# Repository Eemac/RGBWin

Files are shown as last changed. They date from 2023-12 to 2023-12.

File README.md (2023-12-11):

# RGBWin!!
A kW-scale RGBW LED controller for indoor effect lighting. I designed this board in my sophomore year of high school because no low-cost, highly-programmable RGBW solution existed at the time. The two TSSOP parts (PCA9685 16ch PWM controllers) were the first SMT parts I soldered. 

RGB_CTL

## Schematic
My second time using Autodesk Eagle. I didn't know pin labels were a thing, so all wires are directly routed from input to output. I'm so sorry! :P Also, an interesting story about the big power MOSFETs: the only ones I could find that were in my budget came from an obscure eBay listing. I ended up waiting about a month just to put the final parts on the board because shipping took so long! 
Screenshot 2023-12-10 at 8 38 13 PM

## PCB
A fairly decent design, I think. I didn't know about ground pours at the time, so I manually routed large ground traces to all of the power MOSFETs.
PCB

## Design Files/Code, should anyone want.
Provided in the `project` folder.
The Arduino code includes two libraries: `Thread` (https://www.arduino.cc/reference/en/libraries/thread/), and `PCA9685` (https://www.arduino.cc/reference/en/libraries/pca9685-16-channel-pwm-driver-module-library/). These two links have installation instructions and are supported by the Arduino Library manager.

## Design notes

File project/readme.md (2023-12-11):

# Project files

Eagle board/schematic files included as well as a test Arduino .ino file

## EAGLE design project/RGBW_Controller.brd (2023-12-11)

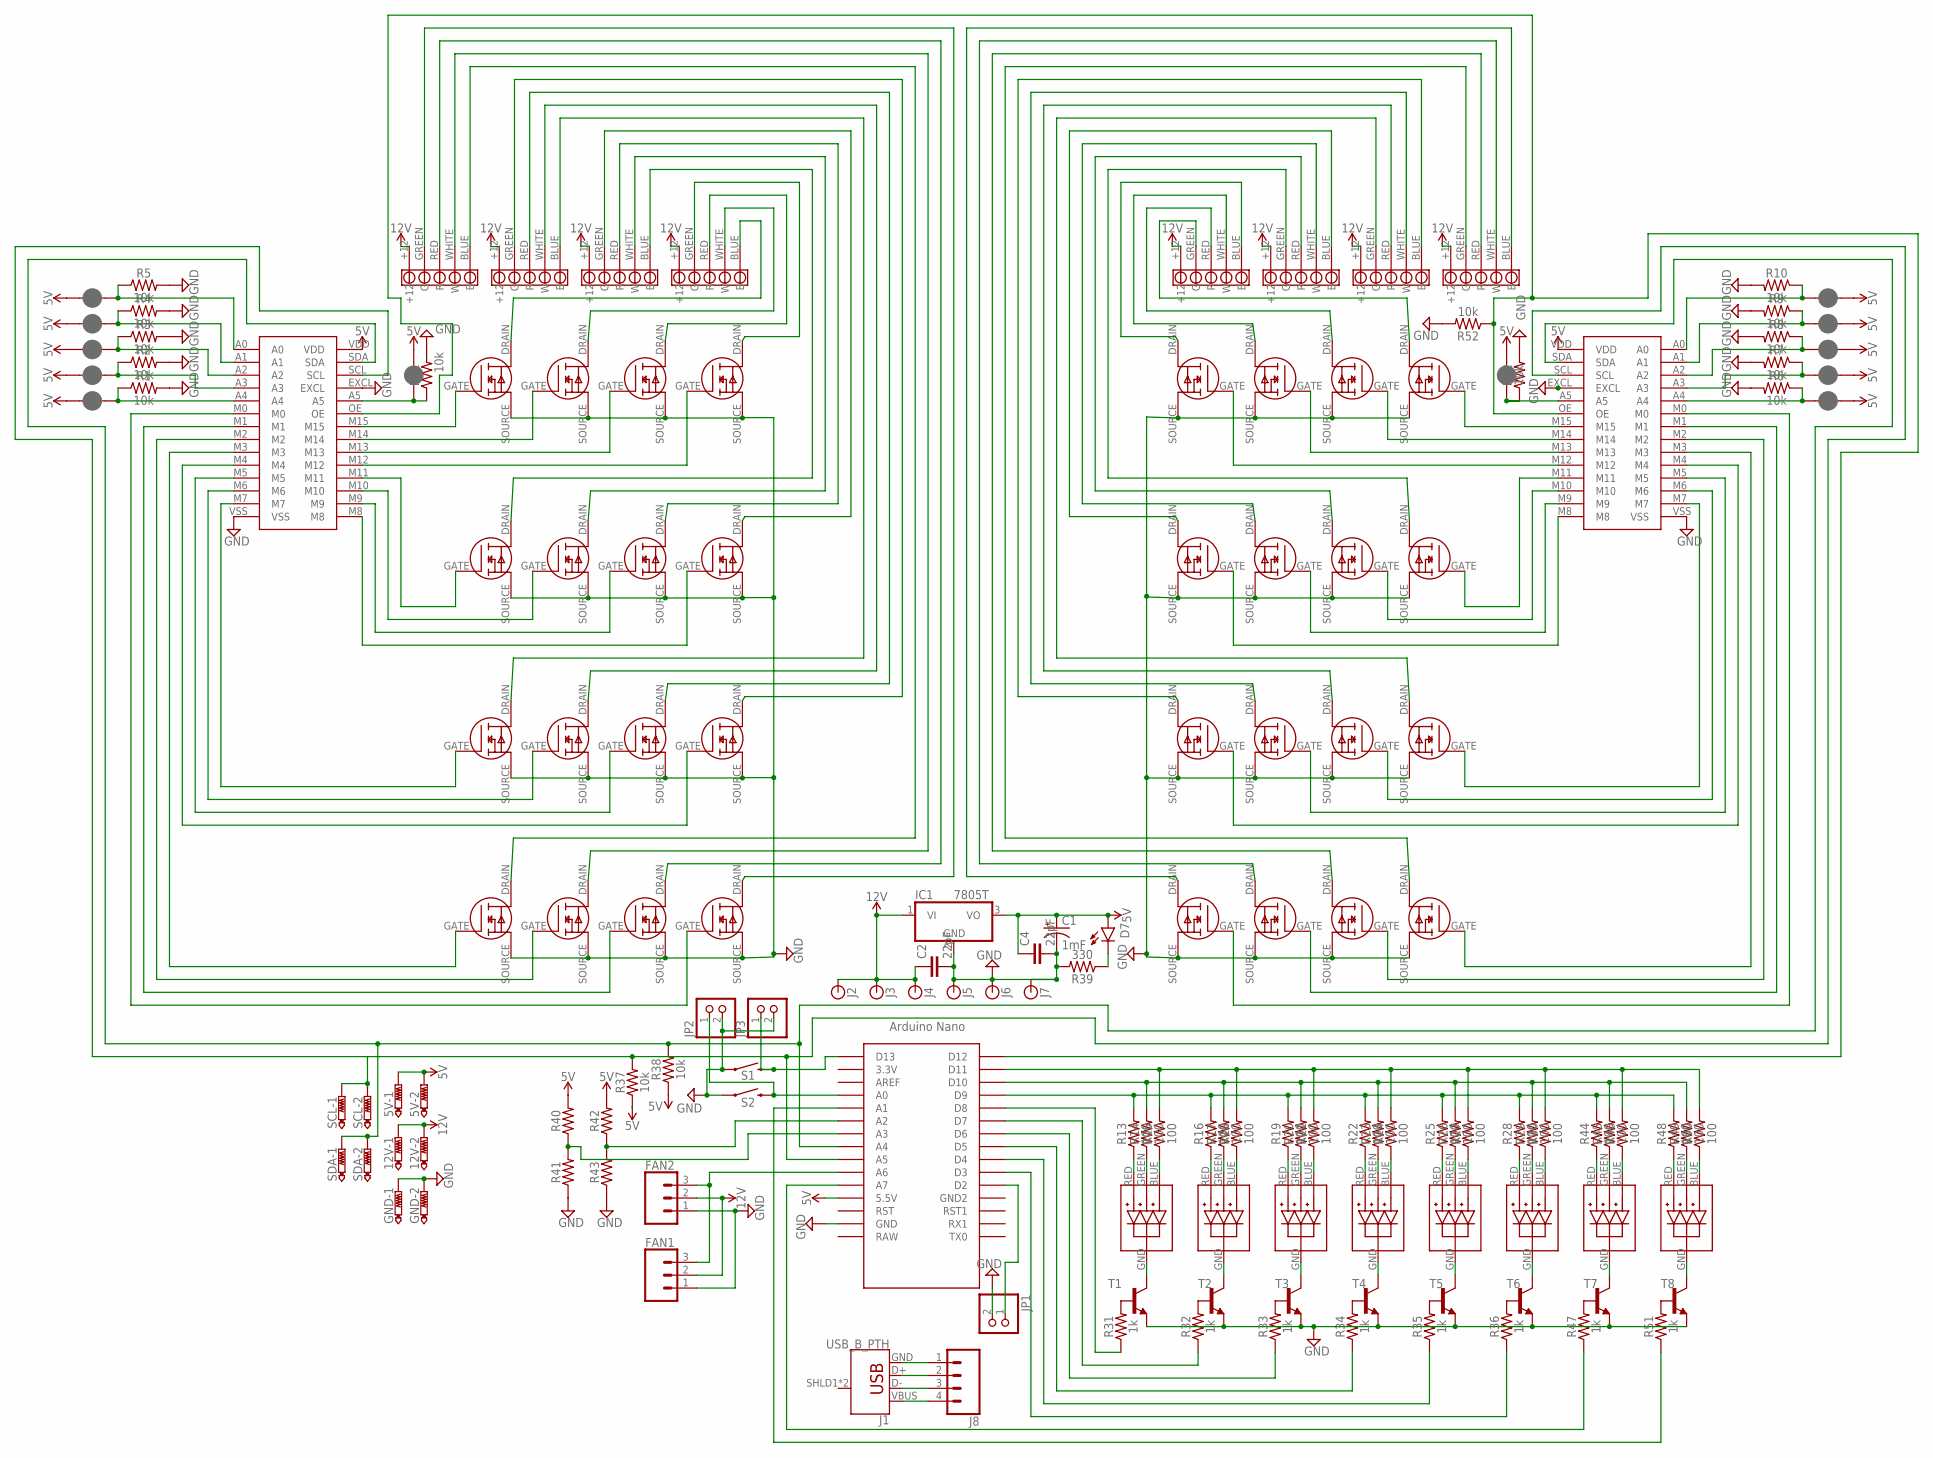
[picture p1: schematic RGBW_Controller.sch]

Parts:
5V, 12V: PTR2; P2-38-17
C1: 1mF; CPOL-RADIAL-5MM-10MM
C2, C4: 22pF; CAP-PTH-2.54
D7: LED5MM; LED_5MM
FAN1, FAN2: CONN_03; 1X03
GND: PTR2; P2-38-17
IC1: 7805T; TO220H
J1: USB_B_PTH; USB-B-PTH
J1_, J2_, J3_, J4_, J5_, J6_, J7_, J8_, J9_, J10_, J11_, J12_: JUMPER-SMT_2_NC_PASTE_SILK; SMT-JUMPER_2_NC_PASTE_SILK
J2, J3, J4, J5, J6, J7: BANANA_CONN
J8: CONN_04; 1X04
JP1, JP2, JP3: PINHD-1X2; 1X02
R1, R2, R3, R4, R5, R6, R7, R8, R9, R10, R11, R12, R37, R38, R52: 10k; AXIAL-0.3
R13, R14, R15, R16, R17, R18, R19, R20, R21, R22, R23, R24, R25, R26, R27, R28, R29, R30, R44, R45, R46, R48, R49, R50: 100; AXIAL-0.3
R31, R32, R33, R34, R35, R36, R47, R51: 1k; AXIAL-0.3
R39: 330; AXIAL-0.3
R40, R42: 10; AXIAL-0.1
R41, R43: 10; AXIAL-0.3
S1, S2: MOMENTARY-SWITCH-SPST-PTH-6.0MM; TACTILE_SWITCH_PTH_6.0MM
SCL: PTR2; P2-38-17
SDA: PTR2; P2-38-17
T1, T2, T3, T4, T5, T6, T7, T8: -NPN-TO92-EBC; TO92-EBC
U$1, U$18: 16CH_PWM
U$2, U$3, U$4, U$5, U$6, U$7, U$8, U$9, U$10, U$11, U$12, U$13, U$14, U$15, U$16, U$17, U$19, U$20, U$21, U$22, U$23, U$24, U$25, U$26, U$27, U$28, U$29, U$30, U$31, U$32, U$33, U$34: MOSFET
U$35: NANO
U$36, U$45, U$46, U$47, U$48, U$49, U$50, U$51: 5MM_RGB; 5MMRGB
U$37, U$38, U$39, U$40, U$41, U$42, U$43, U$44: 5POLE_TERM

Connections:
5V: 5V.TP-1, 5V.TP-2, C1.+, C4.1, D7.A, IC1.3 (VO), J1_.1, J2_.1, J3_.1, J4_.1, J5_.1, J6_.1, J7_.1, J8_.1, J9_.1, J10_.1, J11_.1, J12_.1, R37.P$1 (1), R38.P$1 (1), R40.P$2 (2), R42.P$2 (2), U$1.VDD, U$18.VDD, U$35.5V (5.5V)
12V: 12V.TP-1, 12V.TP-2, C2.1, FAN1.2, FAN2.2, IC1.1 (VI), J2.P$1, J3.P$1, J4.P$1, U$37.+12, U$38.+12, U$39.+12, U$40.+12, U$41.+12, U$42.+12, U$43.+12, U$44.+12
GND: C1.-, C2.2, C4.2, FAN1.1, FAN2.1, GND.TP-1, GND.TP-2, IC1.2 (GND), J5.P$1, J6.P$1, J7.P$1, JP1.2, JP2.2, JP3.2, R1.P$2 (2), R2.P$2 (2), R3.P$2 (2), R4.P$2 (2), R5.P$2 (2), R6.P$2 (2), R7.P$2 (2), R8.P$2 (2), R9.P$2 (2), R10.P$2 (2), R11.P$2 (2), R12.P$2 (2), R39.P$2 (2), R41.P$1 (1), R43.P$1 (1), R52.P$2 (2), S1.1, S2.1, T1.E, T2.E, T3.E, T4.E, T5.E, T6.E, T7.E, T8.E, U$1.EXCL, U$1.VSS, U$2.SOURCE, U$3.SOURCE, U$4.SOURCE, U$5.SOURCE, U$6.SOURCE, U$7.SOURCE, U$8.SOURCE, U$9.SOURCE, U$10.SOURCE, U$11.SOURCE, U$12.SOURCE, U$13.SOURCE, U$14.SOURCE, U$15.SOURCE, U$16.SOURCE, U$17.SOURCE, U$18.EXCL, U$18.VSS, U$19.SOURCE, U$20.SOURCE, U$21.SOURCE, U$22.SOURCE, U$23.SOURCE, U$24.SOURCE, U$25.SOURCE, U$26.SOURCE, U$27.SOURCE, U$28.SOURCE, U$29.SOURCE, U$30.SOURCE, U$31.SOURCE, U$32.SOURCE, U$33.SOURCE, U$34.SOURCE, U$35.GND
unnamed: J12_.2, R12.P$1 (1), U$18.A5
unnamed: R15.P$2 (2), R18.P$2 (2), R21.P$2 (2), R24.P$2 (2), R27.P$2 (2), R30.P$2 (2), R46.P$2 (2), R50.P$2 (2), U$35.D11
unnamed: R13.P$1 (1), U$36.RED
unnamed: R14.P$1 (1), U$36.GREEN
unnamed: J6_.2, R11.P$1 (1), U$1.A5
unnamed: R15.P$1 (1), U$36.BLUE
unnamed: U$18.M15, U$19.GATE
unnamed: U$18.M14, U$20.GATE
unnamed: U$18.M13, U$21.GATE
unnamed: U$1.M15, U$2.GATE
unnamed: U$1.M14, U$3.GATE
unnamed: U$1.M13, U$4.GATE
unnamed: U$1.M12, U$5.GATE
unnamed: D7.K (C), R39.P$1 (1)
unnamed: U$2.DRAIN, U$43.BLUE (B)
unnamed: R16.P$1 (1), U$45.RED
unnamed: R17.P$1 (1), U$45.GREEN
unnamed: J1_.2, R5.P$1 (1), U$1.A0
unnamed: U$1.M11, U$6.GATE
unnamed: U$1.M10, U$7.GATE
unnamed: U$1.M9, U$8.GATE
unnamed: U$1.M8, U$9.GATE
unnamed: R18.P$1 (1), U$45.BLUE
unnamed: R19.P$1 (1), U$46.RED
unnamed: R20.P$1 (1), U$46.GREEN
unnamed: R21.P$1 (1), U$46.BLUE
unnamed: U$18.M12, U$22.GATE
unnamed: U$1.M7, U$10.GATE
unnamed: U$1.M6, U$11.GATE
unnamed: U$1.M5, U$12.GATE
unnamed: U$1.M4, U$13.GATE
unnamed: R22.P$1 (1), U$47.RED
unnamed: R23.P$1 (1), U$47.GREEN
unnamed: R24.P$1 (1), U$47.BLUE
unnamed: R25.P$1 (1), U$48.RED
unnamed: U$22.DRAIN, U$44.BLUE (B)
unnamed: U$1.M3, U$14.GATE
unnamed: U$1.M2, U$15.GATE
unnamed: U$1.M1, U$16.GATE
unnamed: U$1.M0, U$17.GATE
unnamed: R26.P$1 (1), U$48.GREEN
unnamed: R27.P$1 (1), U$48.BLUE
unnamed: R28.P$1 (1), U$49.RED
unnamed: R29.P$1 (1), U$49.GREEN
unnamed: U$21.DRAIN, U$44.WHITE (W)
unnamed: U$20.DRAIN, U$44.RED (R)
unnamed: U$19.DRAIN, U$44.GREEN (G)
unnamed: J2_.2, R4.P$1 (1), U$1.A1
unnamed: U$18.M11, U$23.GATE
unnamed: U$18.M10, U$24.GATE
unnamed: U$18.M9, U$25.GATE
unnamed: U$18.M8, U$26.GATE
unnamed: U$26.DRAIN, U$42.BLUE (B)
unnamed: U$25.DRAIN, U$42.WHITE (W)
unnamed: U$24.DRAIN, U$42.RED (R)
unnamed: U$23.DRAIN, U$42.GREEN (G)
unnamed: U$18.M7, U$27.GATE
unnamed: U$18.M6, U$28.GATE
unnamed: U$18.M5, U$29.GATE
unnamed: U$18.M4, U$30.GATE
unnamed: U$30.DRAIN, U$41.BLUE (B)
unnamed: U$29.DRAIN, U$41.WHITE (W)
unnamed: U$28.DRAIN, U$41.RED (R)
unnamed: U$27.DRAIN, U$41.GREEN (G)
unnamed: U$18.M3, U$31.GATE
unnamed: U$18.M2, U$32.GATE
unnamed: U$18.M1, U$33.GATE
unnamed: U$18.M0, U$34.GATE
unnamed: U$34.DRAIN, U$40.BLUE (B)
unnamed: U$33.DRAIN, U$40.WHITE (W)
unnamed: U$32.DRAIN, U$40.RED (R)
unnamed: U$31.DRAIN, U$40.GREEN (G)
unnamed: R30.P$1 (1), U$49.BLUE
unnamed: JP3.1, S1.3 (2), U$35.D13
unnamed: JP2.1, S2.3 (2), U$35.A0
unnamed: T6.C, U$49.GND
unnamed: T5.C, U$48.GND
unnamed: T4.C, U$47.GND
unnamed: J3_.2, R3.P$1 (1), U$1.A2
unnamed: J4_.2, R2.P$1 (1), U$1.A3
unnamed: J5_.2, R1.P$1 (1), U$1.A4
unnamed: J7_.2, R10.P$1 (1), U$18.A0
unnamed: J8_.2, R9.P$1 (1), U$18.A1
unnamed: J9_.2, R8.P$1 (1), U$18.A2
unnamed: J10_.2, R7.P$1 (1), U$18.A3
unnamed: J11_.2, R6.P$1 (1), U$18.A4
unnamed: T3.C, U$46.GND
unnamed: T2.C, U$45.GND
unnamed: T1.C, U$36.GND
unnamed: J1.GND, J8.1
unnamed: J1.VBUS, J8.4
unnamed: J1.D-, J8.3
unnamed: J1.D+, J8.2
unnamed: R40.P$1 (1), R41.P$2 (2), U$35.A3
unnamed: R42.P$1 (1), R43.P$2 (2), U$35.A2
unnamed: FAN1.3, FAN2.3, U$35.A6
unnamed: R52.P$1 (1), U$1.OE, U$18.OE, U$35.D12
unnamed: R13.P$2 (2), R16.P$2 (2), R19.P$2 (2), R22.P$2 (2), R25.P$2 (2), R28.P$2 (2), R44.P$2 (2), R48.P$2 (2), U$35.D9
unnamed: JP1.1, U$35.D2
unnamed: R37.P$2 (2), SCL.TP-1, SCL.TP-2, U$1.SCL, U$18.SCL, U$35.A5
unnamed: R38.P$2 (2), SDA.TP-1, SDA.TP-2, U$1.SDA, U$18.SDA, U$35.A4
unnamed: R47.P$2 (2), T7.B
unnamed: R47.P$1 (1), U$35.A7
unnamed: R44.P$1 (1), U$50.RED
unnamed: R45.P$1 (1), U$50.GREEN
unnamed: R46.P$1 (1), U$50.BLUE
unnamed: R31.P$1 (1), U$35.D8
unnamed: R31.P$2 (2), T1.B
unnamed: R32.P$2 (2), T2.B
unnamed: R33.P$2 (2), T3.B
unnamed: R34.P$2 (2), T4.B
unnamed: R35.P$2 (2), T5.B
unnamed: R36.P$2 (2), T6.B
unnamed: R32.P$1 (1), U$35.D7
unnamed: R33.P$1 (1), U$35.D6
unnamed: R34.P$1 (1), U$35.D5
unnamed: R35.P$1 (1), U$35.D4
unnamed: R36.P$1 (1), U$35.D3
unnamed: U$17.DRAIN, U$37.GREEN (G)
unnamed: U$16.DRAIN, U$37.RED (R)
unnamed: U$15.DRAIN, U$37.WHITE (W)
unnamed: U$14.DRAIN, U$37.BLUE (B)
unnamed: T7.C, U$50.GND
unnamed: U$13.DRAIN, U$38.GREEN (G)
unnamed: U$12.DRAIN, U$38.RED (R)
unnamed: U$11.DRAIN, U$38.WHITE (W)
unnamed: U$10.DRAIN, U$38.BLUE (B)
unnamed: U$9.DRAIN, U$39.GREEN (G)
unnamed: U$8.DRAIN, U$39.RED (R)
unnamed: U$7.DRAIN, U$39.WHITE (W)
unnamed: U$6.DRAIN, U$39.BLUE (B)
unnamed: U$5.DRAIN, U$43.GREEN (G)
unnamed: U$4.DRAIN, U$43.RED (R)
unnamed: U$3.DRAIN, U$43.WHITE (W)
unnamed: R14.P$2 (2), R17.P$2 (2), R20.P$2 (2), R23.P$2 (2), R26.P$2 (2), R29.P$2 (2), R45.P$2 (2), R49.P$2 (2), U$35.D10
unnamed: R51.P$2 (2), T8.B
unnamed: R51.P$1 (1), U$35.A1
unnamed: R48.P$1 (1), U$51.RED
unnamed: R49.P$1 (1), U$51.GREEN
unnamed: R50.P$1 (1), U$51.BLUE
unnamed: T8.C, U$51.GND

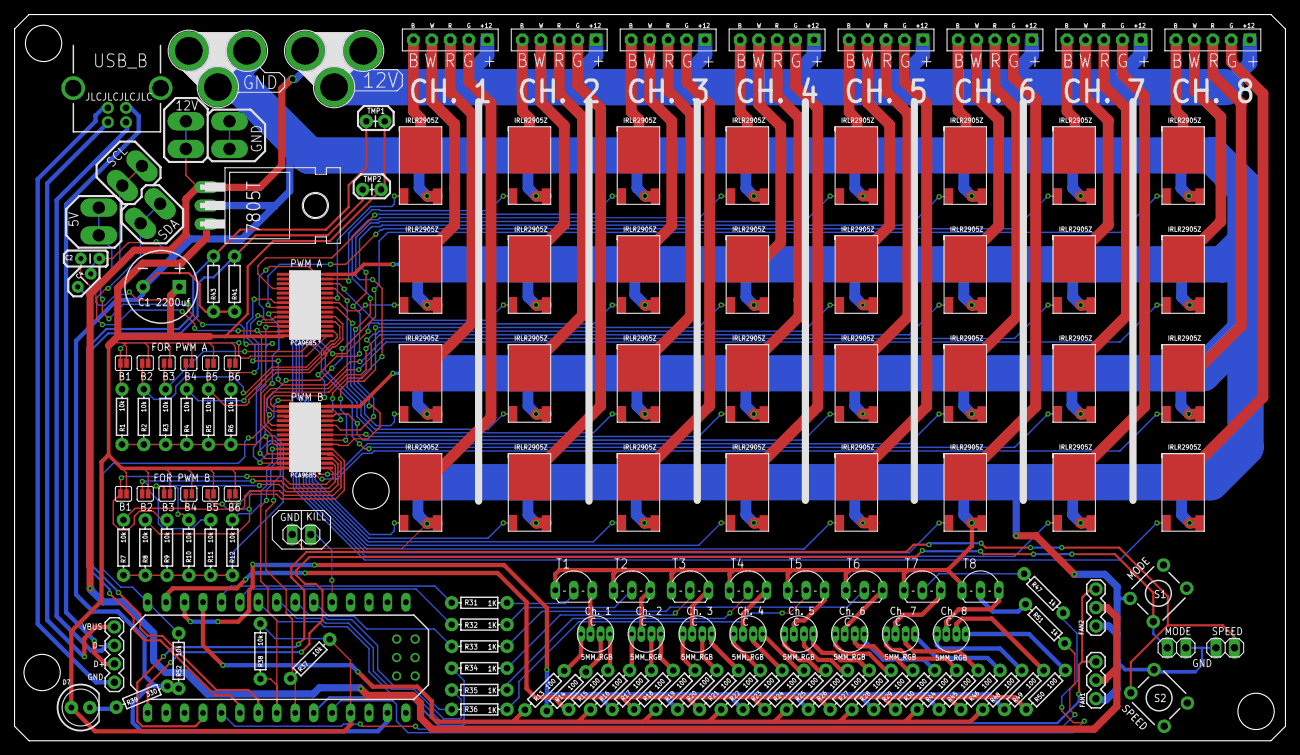
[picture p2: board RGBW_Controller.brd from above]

Board: 2 copper layers, 175.0 x 100.0 mm, 148 parts (0 on the bottom side), 144 nets.

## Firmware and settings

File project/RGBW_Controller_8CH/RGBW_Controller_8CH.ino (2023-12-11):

#include <Wire.h>
#include <PCA9685.h>
#include <Thread.h>

PCA9685 pwm1;
PCA9685 pwm2;

Thread StatusRGB = Thread();

String newLed;

int n = 0;
int tickSpeed = 4;
int allUpTickCounter = 0;
int updateChannel = 0;

static const uint8_t StatusChannel[] = {8, 7, 6, 5, 4, 3, A3, A1};
int statusCounter = 0;

int StatusCh1[] = {0,0,0,0};
int StatusCh2[] = {0,0,0,0};
int StatusCh3[] = {0,0,0,0};
int StatusCh4[] = {0,0,0,0};
int StatusCh5[] = {0,0,0,0};
int StatusCh6[] = {0,0,0,0};
int StatusCh7[] = {0,0,0,0};
int StatusCh8[] = {0,0,0,0};

//Change 1 Ch    0-8       0-4096    0-4096    0-4096    0-4096
void tickRGB(int channel, int red, int green, int blue, int white) { 
    //channel range = 0-7 (1,2,3,7 on pwm1) (4,5,6,8 on pwm2)
    //color ranges = 0-4096
    
    if (channel == 1)
    {
      pwm1.setChannelPWM(3, blue);
      pwm1.setChannelPWM(2, white);
      pwm1.setChannelPWM(1, red);
      pwm1.setChannelPWM(0, green);
      
      StatusCh1[0] = blue;
      StatusCh1[1] = white;
      StatusCh1[2] = red;
      StatusCh1[3] = green;
    }
    if (channel == 2)
    {
      pwm1.setChannelPWM(7, blue);
      pwm1.setChannelPWM(6, white);
      pwm1.setChannelPWM(5, red);
      pwm1.setChannelPWM(4, green);
      
      StatusCh2[0] = blue;
      StatusCh2[1] = white;
      StatusCh2[2] = red;
      StatusCh2[3] = green;
    }
    if (channel == 3)
    {
      pwm1.setChannelPWM(11, blue);
      pwm1.setChannelPWM(10, white);
      pwm1.setChannelPWM(9, red);
      pwm1.setChannelPWM(8, green);

      StatusCh3[0] = blue;
      StatusCh3[1] = white;
      StatusCh3[2] = red;
      StatusCh3[3] = green;
    }
    if (channel == 4)
    {
      pwm2.setChannelPWM(0, blue);
      pwm2.setChannelPWM(1, white);
      pwm2.setChannelPWM(2, red);
      pwm2.setChannelPWM(3, green);
      
      StatusCh4[0] = blue;
      StatusCh4[1] = white;
      StatusCh4[2] = red;
      StatusCh4[3] = green;
    }
    if (channel == 5)
    {
      pwm2.setChannelPWM(4, blue);
      pwm2.setChannelPWM(5, white);
      pwm2.setChannelPWM(6, red);
      pwm2.setChannelPWM(7, green);
      
      StatusCh5[0] = blue;
      StatusCh5[1] = white;
      StatusCh5[2] = red;
      StatusCh5[3] = green;
    }
    if (channel == 6)
    {
      pwm2.setChannelPWM(8, blue);
      pwm2.setChannelPWM(9, white);
      pwm2.setChannelPWM(10, red);
      pwm2.setChannelPWM(11, green);
      
      StatusCh6[0] = blue;
      StatusCh6[1] = white;
      StatusCh6[2] = red;
      StatusCh6[3] = green;
    }
    if (channel == 7)
    {
      pwm1.setChannelPWM(15, blue);
      pwm1.setChannelPWM(14, white);
      pwm1.setChannelPWM(13, red);
      pwm1.setChannelPWM(12, green);
      
      StatusCh7[0] = blue;
      StatusCh7[1] = white;
      StatusCh7[2] = red;
      StatusCh7[3] = green;
    }
    if (channel == 8)
    {
      pwm2.setChannelPWM(12, blue);
      pwm2.setChannelPWM(13, white);
      pwm2.setChannelPWM(14, red);
      pwm2.setChannelPWM(15, green);
      
      StatusCh8[0] = blue;
      StatusCh8[1] = white;
      StatusCh8[2] = red;
      StatusCh8[3] = green;
    }
  }

//LEDs Up     0-4096         0-4096         0-4096       0-4096          0-4096               0-4096                   0-4096
void allUp(int initRed, int initGreen, int initBlue, int initWhite, int tickSpeed = 1, int minBrightness = 0, int maxBrightness = 4096) {

  float redMultiplier = float(initRed) / 4096;
  float greenMultiplier = float(initGreen) / 4096;
  float blueMultiplier = float(initBlue) / 4096;
  float whiteMultiplier = float(initWhite) / 4096;

  for(allUpTickCounter = minBrightness; allUpTickCounter <= maxBrightness; allUpTickCounter = allUpTickCounter + tickSpeed) {

    int red = int(allUpTickCounter * redMultiplier);
    int green = int(allUpTickCounter * greenMultiplier);
    int blue = int(allUpTickCounter * blueMultiplier);
    int white = int(allUpTickCounter * whiteMultiplier);
  
    uint16_t pwms1[16];
    pwms1[0] = green;
    pwms1[1] = red;
    pwms1[2] = white;
    pwms1[3] = blue;
    pwms1[4] = green;
    pwms1[5] = red;
    pwms1[6] = white;
    pwms1[7] = blue;
    pwms1[8] = green;
    pwms1[9] = red;
    pwms1[10] = white;
    pwms1[11] = blue;
    pwms1[12] = green;
    pwms1[13] = red;
    pwms1[14] = white;
    pwms1[15] = blue;

    uint16_t pwms2[16];
    pwms2[0] = blue;
    pwms2[1] = white;
    pwms2[2] = red;
    pwms2[3] = green;
    pwms2[4] = blue;
    pwms2[5] = white;
    pwms2[6] = red;
    pwms2[7] = green;
    pwms2[8] = blue;
    pwms2[9] = white;
    pwms2[10] = red;
    pwms2[11] = green;
    pwms2[12] = blue;
    pwms2[13] = white;
    pwms2[14] = red;
    pwms2[15] = green;

    pwm1.setChannelsPWM(0, 16, pwms1);
    pwm2.setChannelsPWM(0, 16, pwms2);

    for(statusCounter = 0; statusCounter < 8; statusCounter++) {
      analogWrite(9, ((red / 32) + (white / 32)));
      analogWrite(10, ((green / 32) + (white / 32)));
      analogWrite(11, ((blue / 32) + (white / 32)));
      digitalWrite(StatusChannel[statusCounter], HIGH);
    }
    if (allUpTickCounter == maxBrightness) {
      StatusCh1[0] = blue; StatusCh1[1] = white; StatusCh1[2] = red; StatusCh1[3] = green;
      StatusCh2[0] = blue; StatusCh2[1] = white; StatusCh2[2] = red; StatusCh2[3] = green;
      StatusCh3[0] = blue; StatusCh3[1] = white; StatusCh3[2] = red; StatusCh3[3] = green;
      StatusCh4[0] = blue; StatusCh4[1] = white; StatusCh4[2] = red; StatusCh4[3] = green;
      StatusCh5[0] = blue; StatusCh5[1] = white; StatusCh5[2] = red; StatusCh5[3] = green;
      StatusCh6[0] = blue; StatusCh6[1] = white; StatusCh6[2] = red; StatusCh6[3] = green;
      StatusCh7[0] = blue; StatusCh7[1] = white; StatusCh7[2] = red; StatusCh7[3] = green;
      StatusCh8[0] = blue; StatusCh8[1] = white; StatusCh8[2] = red; StatusCh8[3] = green;

      for(statusCounter = 0; statusCounter < 8; statusCounter++) {
        digitalWrite(StatusChannel[statusCounter], LOW);
      }
    }
  }
}
//LEDs Down    0-4096         0-4096         0-4096       0-4096          0-4096               0-4096                   0-4096
void allDown(int initRed, int initGreen, int initBlue, int initWhite, int tickSpeed = 1, int minBrightness = 0, int maxBrightness = 4096) {

  float redMultiplier = float(initRed) / 4096;
  float greenMultiplier = float(initGreen) / 4096;
  float blueMultiplier = float(initBlue) / 4096;
  float whiteMultiplier = float(initWhite) / 4096;

  for(allUpTickCounter = maxBrightness; allUpTickCounter >= minBrightness; allUpTickCounter = allUpTickCounter - tickSpeed) {

    int red = int(allUpTickCounter * redMultiplier);
    int green = int(allUpTickCounter * greenMultiplier);
    int blue = int(allUpTickCounter * blueMultiplier);
    int white = int(allUpTickCounter * whiteMultiplier);
  
    uint16_t pwms1[16];
    pwms1[0] = green;
    pwms1[1] = red;
    pwms1[2] = white;
    pwms1[3] = blue;
    pwms1[4] = green;
    pwms1[5] = red;
    pwms1[6] = white;
    pwms1[7] = blue;
    pwms1[8] = green;
    pwms1[9] = red;
    pwms1[10] = white;
    pwms1[11] = blue;
    pwms1[12] = green;
    pwms1[13] = red;
    pwms1[14] = white;
    pwms1[15] = blue;

    uint16_t pwms2[16];
    pwms2[0] = blue;
    pwms2[1] = white;
    pwms2[2] = red;
    pwms2[3] = green;
    pwms2[4] = blue;
    pwms2[5] = white;
    pwms2[6] = red;
    pwms2[7] = green;
    pwms2[8] = blue;
    pwms2[9] = white;
    pwms2[10] = red;
    pwms2[11] = green;
    pwms2[12] = blue;
    pwms2[13] = white;
    pwms2[14] = red;
    pwms2[15] = green;

    pwm1.setChannelsPWM(0, 16, pwms1);
    pwm2.setChannelsPWM(0, 16, pwms2);

    for(statusCounter = 0; statusCounter < 8; statusCounter++) {
      analogWrite(9, ((red / 32) + (white / 32)));
      analogWrite(10, ((green / 32) + (white / 32)));
      analogWrite(11, ((blue / 32) + (white / 32)));
      digitalWrite(StatusChannel[statusCounter], HIGH);
    }
    if (allUpTickCounter == minBrightness) {
      StatusCh1[0] = blue; StatusCh1[1] = white; StatusCh1[2] = red; StatusCh1[3] = green;
      StatusCh2[0] = blue; StatusCh2[1] = white; StatusCh2[2] = red; StatusCh2[3] = green;
      StatusCh3[0] = blue; StatusCh3[1] = white; StatusCh3[2] = red; StatusCh3[3] = green;
      StatusCh4[0] = blue; StatusCh4[1] = white; StatusCh4[2] = red; StatusCh4[3] = green;
      StatusCh5[0] = blue; StatusCh5[1] = white; StatusCh5[2] = red; StatusCh5[3] = green;
      StatusCh6[0] = blue; StatusCh6[1] = white; StatusCh6[2] = red; StatusCh6[3] = green;
      StatusCh7[0] = blue; StatusCh7[1] = white; StatusCh7[2] = red; StatusCh7[3] = green;
      StatusCh8[0] = blue; StatusCh8[1] = white; StatusCh8[2] = red; StatusCh8[3] = green;
      
      for(statusCounter = 0; statusCounter < 8; statusCounter++) {
        digitalWrite(StatusChannel[statusCounter], LOW);
      }
    }
  }
}

void statusLed() {

  if (updateChannel == 1) {
    digitalWrite(StatusChannel[7], LOW);
    analogWrite(9, ((StatusCh1[2] / 32) + (StatusCh1[1] / 33)));
    analogWrite(10, ((StatusCh1[3] / 32) + (StatusCh1[1] / 33)));
    analogWrite(11, ((StatusCh1[0] / 32) + (StatusCh1[1] / 33)));
    digitalWrite(StatusChannel[0], HIGH);
  }

  if (updateChannel == 2) {
    digitalWrite(StatusChannel[0], LOW);
    analogWrite(9, ((StatusCh2[2] / 32) + (StatusCh2[1] / 33)));
    analogWrite(10, ((StatusCh2[3] / 32) + (StatusCh2[1] / 33)));
    analogWrite(11, ((StatusCh2[0] / 32) + (StatusCh2[1] / 33)));
    digitalWrite(StatusChannel[1], HIGH);
  }

  if (updateChannel == 3) {
    digitalWrite(StatusChannel[1], LOW);
    analogWrite(9, ((StatusCh3[2] / 32) + (StatusCh3[1] / 33)));
    analogWrite(10, ((StatusCh3[3] / 32) + (StatusCh3[1] / 33)));
    analogWrite(11, ((StatusCh3[0] / 32) + (StatusCh3[1] / 33)));
    digitalWrite(StatusChannel[2], HIGH);
  }

  if (updateChannel == 4) {
    digitalWrite(StatusChannel[2], LOW);
    analogWrite(9, ((StatusCh4[2] / 32) + (StatusCh4[1] / 33)));
    analogWrite(10, ((StatusCh4[3] / 32) + (StatusCh4[1] / 33)));
    analogWrite(11, ((StatusCh4[0] / 32) + (StatusCh4[1] / 33)));
    digitalWrite(StatusChannel[3], HIGH);
  }

  if (updateChannel == 5) {
    digitalWrite(StatusChannel[3], LOW);
    analogWrite(9, ((StatusCh5[2] / 32) + (StatusCh5[1] / 33)));
    analogWrite(10, ((StatusCh5[3] / 32) + (StatusCh5[1] / 33)));
    analogWrite(11, ((StatusCh5[0] / 32) + (StatusCh5[1] / 33)));
    digitalWrite(StatusChannel[4], HIGH);
  }

  if (updateChannel == 6) {
    digitalWrite(StatusChannel[4], LOW);
    analogWrite(9, ((StatusCh6[2] / 32) + (StatusCh6[1] / 33)));
    analogWrite(10, ((StatusCh6[3] / 32) + (StatusCh6[1] / 33)));
    analogWrite(11, ((StatusCh6[0] / 32) + (StatusCh6[1] / 33)));
    digitalWrite(StatusChannel[5], HIGH);
  }
  
  if (updateChannel == 7) {
    digitalWrite(StatusChannel[5], LOW);
    analogWrite(9, ((StatusCh7[2] / 32) + (StatusCh7[1] / 33)));
    analogWrite(10, ((StatusCh7[3] / 32) + (StatusCh7[1] / 33)));
    analogWrite(11, ((StatusCh7[0] / 32) + (StatusCh7[1] / 33)));
    digitalWrite(StatusChannel[6], HIGH);
  }

  if (updateChannel == 8) {
    digitalWrite(StatusChannel[6], LOW);
    analogWrite(9, ((StatusCh8[2] / 32) + (StatusCh8[1] / 33)));
    analogWrite(10, ((StatusCh8[3] / 32) + (StatusCh8[1] / 33)));
    analogWrite(11, ((StatusCh8[0] / 32) + (StatusCh8[1] / 33)));
    digitalWrite(StatusChannel[7], HIGH);
  }
  
  if(StatusRGB.shouldRun()) {
    StatusRGB.run();
  }
}

void statusLedHelper() {
  updateChannel ++;
  
  if(updateChannel == 9) {
    updateChannel = 1;
  }
}

void doSerialUpdate() {
  //Check for incoming serial data
  while (Serial.available()) {
    delayMicroseconds(100); 
    char incomingChar = Serial.read();
    newLed += incomingChar;
  }
  
  //Example incoming string: t14096123404931472
  //Example blown up: t 1 4096 1234 0493 1472
  if(newLed.indexOf("t") > -1) { 
    tickRGB((newLed.substring(1,2)).toInt(), (newLed.substring(2,6)).toInt(), (newLed.substring(6,10)).toInt(), (newLed.substring(10,14)).toInt(), (newLed.substring(14,18)).toInt());
    updateChannel = 0;
    newLed = "";
  }
  
  //Example incoming string: u4096409640964096000100004096
  //Example blown up: u 4096 4096 4096 4096 0001 0000 4096
  else if(newLed.indexOf("u") > -1) { 
    allUp((newLed.substring(1,5)).toInt(), (newLed.substring(5,9)).toInt(), (newLed.substring(9,13)).toInt(), (newLed.substring(13,17)).toInt(), (newLed.substring(17,21)).toInt(), (newLed.substring(21,25)).toInt(), (newLed.substring(25,29)).toInt());
    updateChannel = 0;
    newLed = "";
  }
    
  //Example incoming string: d4096409640964096000100004096
  //Example blown up: d 4096 4096 4096 4096 0001 0000 4096
  else if(newLed.indexOf("d") > -1) { 
    allDown((newLed.substring(1,5)).toInt(), (newLed.substring(5,9)).toInt(), (newLed.substring(9,13)).toInt(), (newLed.substring(13,17)).toInt(), (newLed.substring(17,21)).toInt(), (newLed.substring(21,25)).toInt(), (newLed.substring(25,29)).toInt());
    updateChannel = 0;
    newLed = "";
  }
}

void otherCrap() {
  
}

void setup() {
  
    Serial.begin(250000);

    Wire.begin();                       // Wire must be started first
    Wire.setClock(400000);              // Supported baud rates are 100kHz, 400kHz, and 1000kHz

    pwm1.resetDevices();       // Software resets all PCA9685 devices on Wire line

    pwm1.init(B000000);        // Address pins A5-A0 set to B000000
    pwm1.setPWMFrequency(1500); // Default is 200Hz, supports 24Hz to 1526Hz

    pwm2.init(B000001);        // Address pins A5-A0 set to B000000
    pwm2.setPWMFrequency(1500); // Default is 200Hz, supports 24Hz to 1526Hz

    pinMode(A1, OUTPUT);
    pinMode(A3, OUTPUT);
    pinMode(3, OUTPUT);
    pinMode(4, OUTPUT);
    pinMode(5, OUTPUT);
    pinMode(6, OUTPUT);
    pinMode(7, OUTPUT);
    pinMode(8, OUTPUT);
    pinMode(9, OUTPUT);
    pinMode(10, OUTPUT);
    pinMode(11, OUTPUT);

    pinMode(13, INPUT_PULLUP);
    pinMode(A0, INPUT_PULLUP);

    pinMode(A6, INPUT);
    pinMode(A7, INPUT);

    StatusRGB.onRun(statusLedHelper);
    StatusRGB.setInterval(333);

    tickRGB(1, 4096, 0, 0, 0);
//    tickRGB(2, 4096, 4096, 0, 0);
//    tickRGB(3, 0, 4096, 0, 0);
//    tickRGB(4, 0, 4096, 4096, 0);
//    tickRGB(5, 0, 0, 4096, 0);
//    tickRGB(6, 4096, 0, 4096, 0);
//    tickRGB(7, 0, 0, 0, 4096);
//    tickRGB(8, 4096, 0, 0, 0);

//    allDown(4096,4096,4096,4096);
    
//    allUp(4096,4096,4096,4096);
   
}

void loop() {
  //See if anything is coming in on the serial port
  doSerialUpdate();
  
  //take care of RGB Status lights
  statusLed();
}

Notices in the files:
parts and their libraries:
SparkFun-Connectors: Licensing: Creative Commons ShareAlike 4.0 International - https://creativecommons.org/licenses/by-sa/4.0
